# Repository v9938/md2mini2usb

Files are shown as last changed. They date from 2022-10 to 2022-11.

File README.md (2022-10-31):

# MD/CyberStick to USB Converter (MD2mini2USB)<BR>Nintendo Switch/MegaDrivemini2 Cyberstickモード対応版  

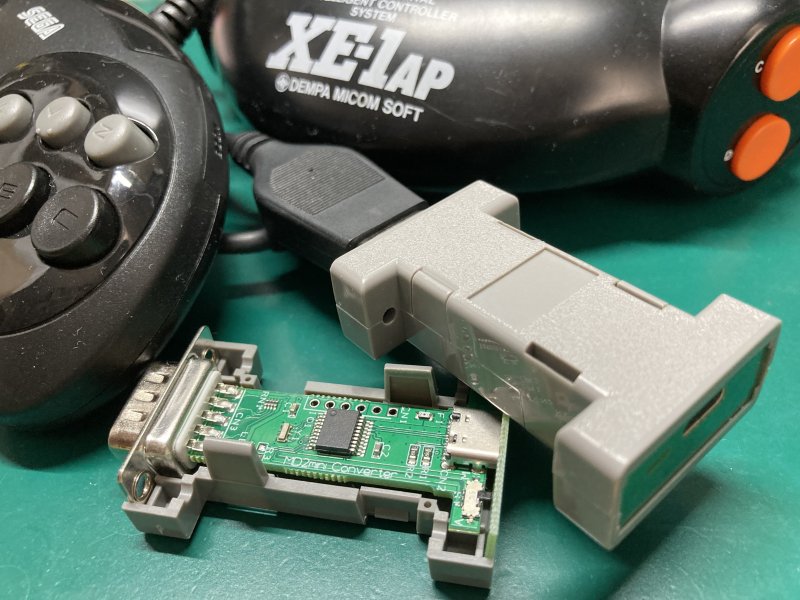
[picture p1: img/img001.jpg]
装置イメージ
  

**「メガドライブ2ミニ対応」 ←→ 「Ninetndo Switch対応」 の切り替えはファームウェア書換が必要です。**  

MD2mini2USBは、ジョイスティックコンバータです。  
メガドライブ対応コントローラ(3ボタン/6ボタン)・SHARP CyberStick(CZ-8NJ2),マイコンソフト XE-1AJ  
のプロトコルを変換し、DirectInput方式のUSBコントローラとして使える様にするコンバータです。  
元々は、メガドライブ2ミニ向けに制作していましたが、Nitendo Switchでも使用できる様になりました。  

現在、接続するゲーム機にあわせて2種類のファームウェアがあります。  
### メガドライブ2ミニ向けファームウェア  
下記コントローラ互換として動作します。  

* SEGA ファイティングパッド6B  
* マイコンソフト　サイバースティック XE1AJ1-USB  

**※ XE1AJ1-USBモードはMegaDrive2mini/Genesis2mini/PC接続のみ対応しています**

### Nintendo Switch向けファームウェア
下記コントローラ互換品として動作します。 

* HORI NSW-063(『ポッ拳 DX』専用コントローラー)  

## ■ 使用例
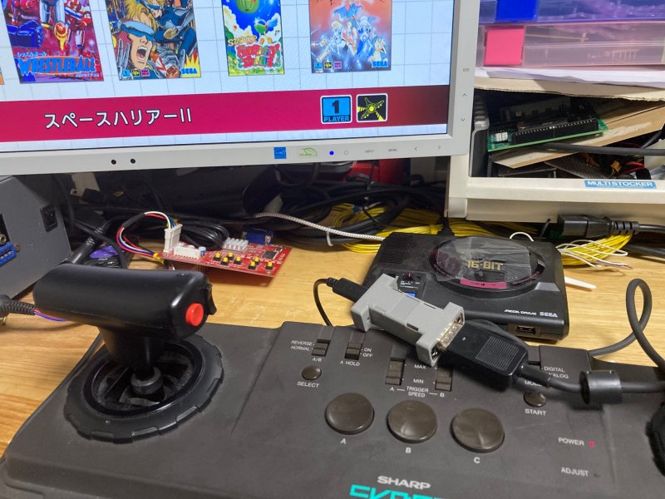
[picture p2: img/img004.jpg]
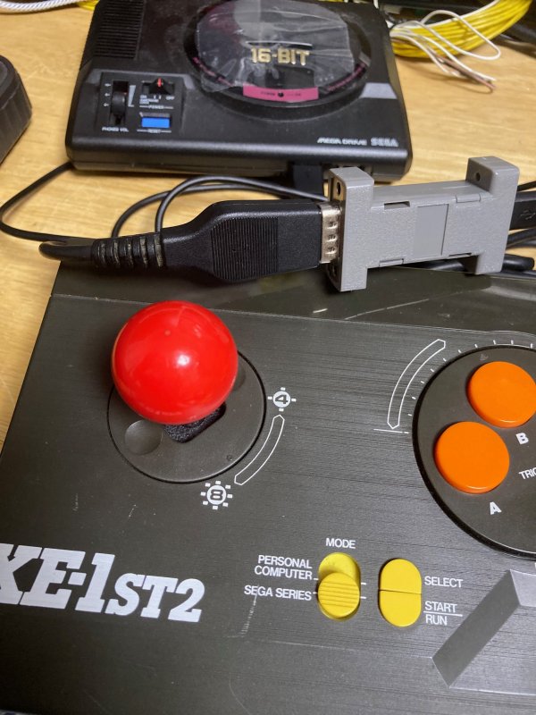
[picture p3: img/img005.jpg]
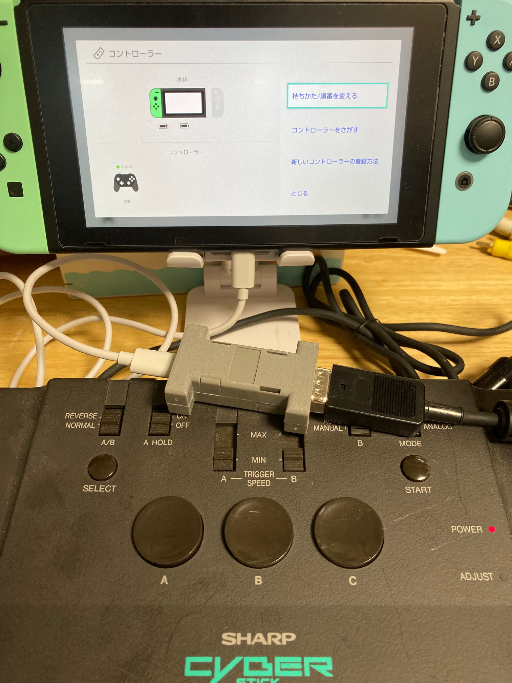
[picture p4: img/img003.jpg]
    

動画については下記URLを参照してください。  
<https://twitter.com/v9938/status/1580212775111909376?s=20&t=MJM-NV-31tJaAHmfy5s3Zw>
<https://twitter.com/v9938/status/1579874855343730689?s=20&t=MJM-NV-31tJaAHmfy5s3Zw>

## ■ 頒布について   

本製品はBoothおよび家電のKENちゃん、BEEPさんにて近日販売予定です。  
(Boothの発送は、週末にまとめて発送になるため、お急ぎの方は他ショップを利用ください)

### BEEP  

<https://www.beep-shop.com/ec/products/detail/28588>

### 家電のKENちゃん  

<https://www.kadenken.com/view/item/000000001480?category_page_id=ct169>

### Booth: (週１回の発送)  

<https://ifc.booth.pm/items/4229656>  
Boothでは先行品販売を実施しません [10/29以降 販売開始予定]  

## ■ 頒布品のメガドラミニ対応版とNintendo Switch対応版の違い

初期に書き込まれているファームウェアだけが異なります。ハードウェアに違いはありません。  
ユーザ側でファームウェアを書き換えることで、双方向の対応版を何回でも行き来できます。

## ■ 先行販売品について

先行販売版はXE1AJ-USBモードは仮実装になっています。  
メガドライブ2ミニ販売後に対応ファームウェアを公開する予定です。  

ユーザにて当該ファームウェアにアップデートをお願いします。  

## ■ 使用方法

1. D-SUB9Pin側に使いたいコントローラを接続します。
2. 先の細いものでコントローラモード切替スイッチを適切なモードにセットします。  
スイッチは、非常に壊れやすいので優しく取り扱いください。  
3. USBコネクタにケーブルを接続して、使用する機器に接続します。  

MegaDrive2miniでCyberStickモードを使う場合はCONTROLLER2に接続してください。　　

**メガドライブコントローラとCyberStickでは、コントローラ側の電源端子が異なります。**  
**コントローラモード切替スイッチは、本機の電源が入っていない状態で切り替えてください。**

| メガドライブコントローラモード | Cyberstickモード(MSX仕様) |  
| - | - |
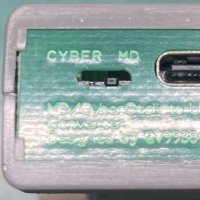
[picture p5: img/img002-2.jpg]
スイッチ位置MD
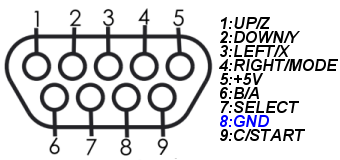
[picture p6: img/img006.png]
DSUB_MD
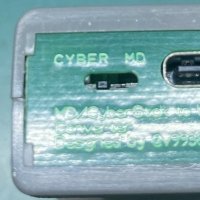
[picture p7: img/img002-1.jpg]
スイッチ位置ATARI
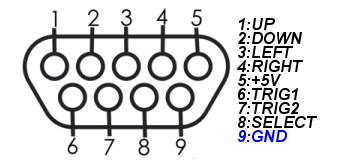
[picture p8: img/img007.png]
DSUB_ATARI
|    |   |

## ■ ボタン配置について

各オリジナルコントローラのボタン配置に準拠しています。設定ソフトにてボタン配置は変更可能です。  
変更した配置は、コントローラのBボタンを押しながらケーブル抜差（電源投入）を行う事で初期値になります。

初期値でのWindows PC上での配置は下記の通りです。

### ●メガドライブ2ミニ向けファームウェア ボタン配置

#### メガドライブコントローラモード(SEGA ファイティングパッド6B互換モード)  

| メガドライブコントローラ | USBコントローラ配置 | 制限事項など |  
| - | - | - |
| スティック | Ｘ軸Ｙ軸 |  |
| Ａ、Ｂ、Ｃボタン | ボタン３、２、６|  |
| Ｘ、Ｙ、Ｚボタン | ボタン４、１、５ | 6ボタン対応コントローラーのみ有効 |
| ＭＯＤＥボタン | ボタン７ | 6ボタン対応コントローラーのみ有効 |
| スタートボタン | ボタン８ |  |

#### CyberStickモード(XE1AJ1-USB互換モード)  

| CyberStick | USBコントローラ配置 | 制限事項など |  
| - | - | - |
| スティック | Ｘ軸Ｙ軸 |  |
| スロットル前後 | Ｚ回転 |  |
| トリガボタンＡ、Ｂ、Ｃ | ボタン１、２、３ |  |
| トリガボタンＤ、Ｅ１、Ｅ２ | ボタン４、５、６ |  |
| トリガボタンＡ'、Ｂ' | ボタン１、２ |  |
| セレクト、スタートボタン | ボタン７、８ | CZ-8NJ2のデジタルモードでは使用できません。 |

#### CyberStickモード(SEGA ファイティングパッド6B互換モード　※Aボタンを押しながらUSBを接続)  

| CyberStick | USBコントローラ配置 | 制限事項など |  
| - | - | - |
| スティック | Ｘ軸Ｙ軸 |  |
| スロットル前後 | － |  |
| トリガボタンＡ、Ｂ、Ｃ | ボタン３、２、７ |  |
| トリガボタンＤ、Ｅ１、Ｅ２ | ボタン４、１、６ |  |
| トリガボタンＡ'、Ｂ' | ボタン３、２ |  |
| セレクト、スタートボタン | ボタン９、１０ | CZ-8NJ2のデジタルモードでは使用できません。 |

### ●Nintendo SWITCH向けファームウェア ボタン配置

#### メガドライブコントローラモード  

| メガドライブコントローラ | コントローラ配置 | 制限事項など |  
| - | - | - |
| スティック | 左アナログスティックＸＹ軸 |  |
| Ａ、Ｂ、Ｃボタン | ボタンＡ、Ｂ、Ｒ|  |
| Ｘ、Ｙ、Ｚボタン | ボタンＸ、Ｙ、Ｌ | 6ボタン対応コントローラーのみ有効 |
| ＭＯＤＥボタン | ボタンＨＯＭＥ | 6ボタン対応コントローラーのみ有効 |
| スタートボタン | ボタン［＋］ |  |

#### CyberStickモード  

| CyberStick | コントローラ配置 | 制限事項など |  
| - | - | - |
| スティック | 左アナログスティックＸＹ軸 |  |
| スロットル前後 | 右アナログスティックＹ軸 |  |
| トリガボタンＡ、Ｂ、Ｃ | ボタンＡ、Ｂ、Ｙ |  |
| トリガボタンＤ、Ｅ１、Ｅ２ | ボタンＸ、Ｒ、Ｌ |  |
| トリガボタンＡ'、Ｂ' | ボタンＡ、Ｂ |  |
| セレクト、スタートボタン | ボタンＨＯＭＥ、［＋］ | CZ-8NJ2のデジタルモードでは使用できません。 |

## ■ 変換遅延について

変換にかかる内部処理時間は、一番時間がかかるメガドライブ6ボタンパッドで使用時で8.5us程度です。  
いずれのモードでもLow Speed USB規格の最小通信単位である1frame(1ms)以内で完了していることを確認しています。  
そのため規格上は変換遅延が無いことになります。  

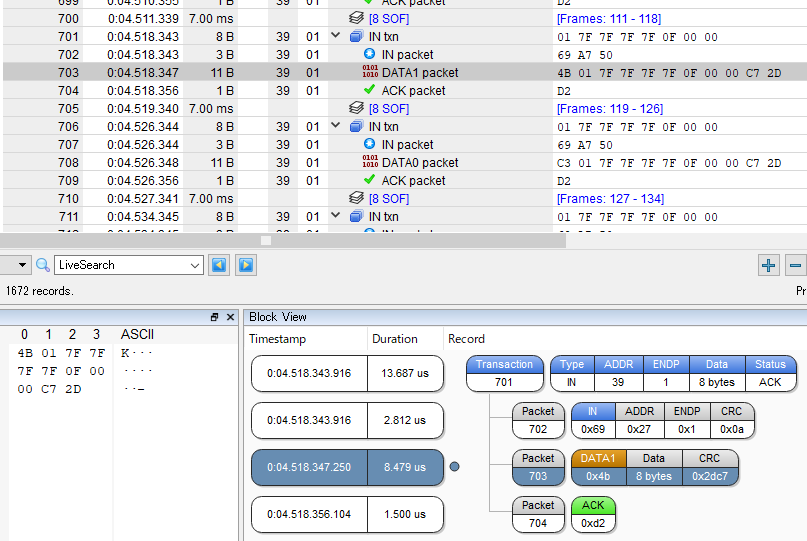
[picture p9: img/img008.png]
USBパケット


## ■ その他の注意点  

オリジナルのコントローラは製造後２０年以上経っています。  
動作不安定の場合は接続コントローラが正常に動作するかを確認をお願いします。

他の接続機器に影響がある場合があるのでコントローラはUSB接続前に接続してください。

コントローラモード切替スイッチ設定を誤ると回路保護のため一定時間電源が入らなくなる場合があります。  
その場合は、数分程度放置後再度接続する様にお願いします。  

## ■ ファームウェアアップデートについて(頒布版のみ対応)

本製品はファームウェアアップデートに対応しています。  
ファームウェアアップデートについては、Windows PCが必要になります。  

1. デバイスを一度取り外します。  
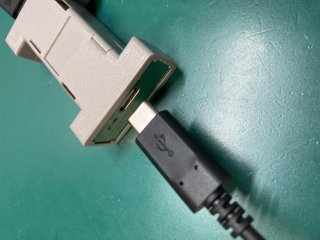
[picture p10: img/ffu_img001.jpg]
FFU1
  

2. Firmware Updateソフトを実行します。デバイスの接続待ち表示になります。  
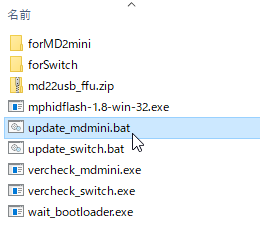
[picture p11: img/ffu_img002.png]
  FFU3  

3. 対応コントローラの［Cボタン］を押したままWindows PCに接続します。  
（コントローラモードスイッチは接続するコントローラに合わせてください。）  
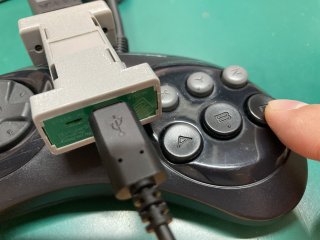
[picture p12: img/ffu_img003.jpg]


4. 正常に認識されると自動的にファームウェア更新が実行されます。  
認識されない場合は3からの手順を実施してください。　　
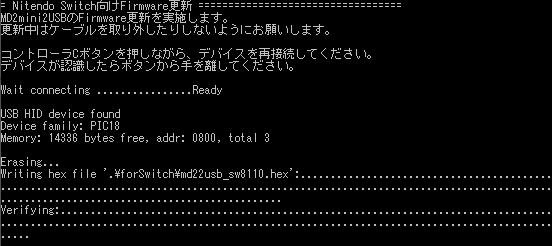
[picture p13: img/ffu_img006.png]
  
5. ファームウェア更新完了表示が出たら、一度デバイスを取り外します。  
更新後、設定の状態によってボタンが正常に動作しない場合があります。  
その場合はBボタンを押しながらUSBケーブルを抜き差しを行いE2PROMを初期化してください。
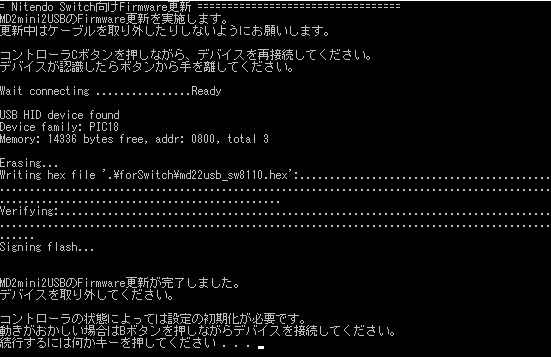
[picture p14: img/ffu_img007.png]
  

### ファームウェア更新/書換ツール

下記URLにてファームウェア更新/書換に必要なツールとファイル一式を頒布しています。  
<https://github.com/v9938/md2mini2usb/raw/main/FFU/md22usb_ffu.zip>

ZIPファイルを解凍後に、下記バッチファイルを実行してください。  

`./FFU/update_mdmini.bat`　メガドライブ2ミニ向けファームウェア更新  
`./FFU/update_switch.bat`　Nintendo Switch向けファームウェア更新  

### ファームウェアVersion確認方法  

ファームウェアVersionについては上記Firmware Updateソフト解凍後に下記手順で確認可能です。

1. 接続しているコントローラを外します。
2. コントローラモード切替スイッチをCyber側にします。
3. Windows PCに接続します。
4. Version確認ソフトで確認します。  

`./FFU/vercheck.exe`

実行画面  

謝辞：  
PID/UIDは、Microchipサブライセンスプログラムにより提供されたものを使用しています。  
ファームウェアアップデート機能には、 莎華(SAKA)さんのHID Bootloader (pic18Non-J)を利用しています。  
<http://www3.airnet.ne.jp/saka/hardware/pic-bootloader/pic-bootloader01.html>  

## ■ XE1AJ1-USB設定ソフトについて

マイコンソフトさんの設定ソフトはBootloaderモードで設定しているため、本製品では使用できません。  
遊び値や移動量設定ができるツールを別途用意しているのでそちらを使用してください。  

※テスト用ツールのXE1AJ-USB_TEST.exe/XE1AJ-USB_TEST_MINI.exeは使えます。  

## ■ ボタン配置について（メガドラミニ用)
ボタン設定ソフトを実行することで各モードでのボタン配置やスティックの遊びや移動量を変更することが可能です。  
設定値は、本体に記録されます。  

メガドライブミニ用ファームウェア向け設定用ソフト
<https://github.com/v9938/md2mini2usb/raw/main/keyconfig/keyconfigMd.exe>  

設定は下記手順で可能です。

1. 接続しているコントローラを外します。
2. コントローラモード切替スイッチをCyber側にします。
3. Windows PCに接続します。
4. 上記ソフトを実行します。

実行すると下記メニューがでます。  
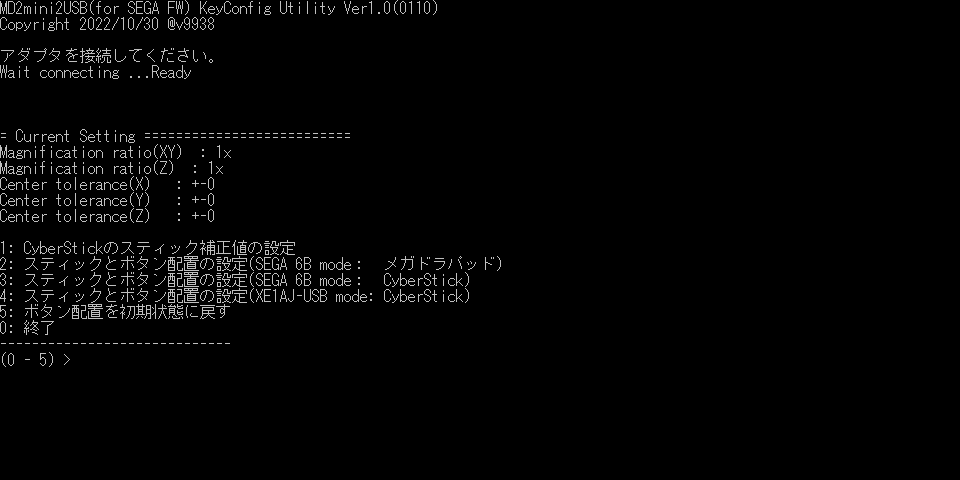
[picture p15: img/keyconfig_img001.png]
  

### メニュー説明  
#### 1: CyberStickのスティック補正値の設定  
アナログコントローラのセンターの遊び量と移動量設定(1～2倍)を設定できます。  
設定は、ジョイスティックのX,Y、Throttleのそれぞれで設定ができます。

#### 2: スティックとボタン配置の設定(SEGA 6B mode：  メガドラパッド)  
メガドライブパッドを接続した時のボタン配置を設定できます。  
ボタン番号はWindows PC上でのボタン番号と一致しています。  
スティックの設定は変更できません。

#### 3: スティックとボタン配置の設定(SEGA 6B mode：  CyberStick)  
SEGA ファイティングパッド6Bモード時のCyberStickのボタン配置を設定できます。  
ボタン番号はWindows PC上でのボタン番号と一致しています。
ジョイスティック、Throttleスティックの設定および値の反転設定ができます。  
ただし、XY Stickは一つしか無い為、どちらかのみが有効になります。  

#### 4: スティックとボタン配置の設定(XE1AJ-USB mode: CyberStick)  
XE1AJ-USBモード時のCyberStickのボタン配置を設定できます。  
ボタン番号はWindows PC上でのボタン番号と一致しています。  
ジョイスティック、Throttleスティックの割りあて設定および値の反転設定ができます。  
XY Stick/Z Stick/Hat Switchに割り当て可能です。重複設定した場合はいずれかのみが有効になります。  

#### 5: ボタン配置を初期状態に戻す  
ボタン配置とコントローラをすべて初期状態に戻します。  

## ■ ボタン配置について（SWITCH用)
ボタン設定ソフトを実行することで各モードでのボタン配置やスティックの遊びや移動量を変更することが可能です。  
設定値は、本体に記録されます。  

Switch用ファームウェア向け設定用ソフト
<https://github.com/v9938/md2mini2usb/raw/main/keyconfig/keyconfigSwitch.exe>  

設定は下記手順で行います。
1. 接続しているコントローラを外します。
2. コントローラモード切替スイッチをCyber側にします。
3. Windows PCに接続します。
4. 上記ソフトを実行します。

### メニュー説明
#### 1: CyberStickのスティック補正値の設定  
アナログコントローラのセンターの遊び量と移動量設定(1～2倍)を設定できます。  
設定は、ジョイスティックのX,Y、Throttleのそれぞれで設定ができます。

#### 2: 2: スティックとボタン配置の設定(SEGAメガドラパッド)  
メガドライブパッドを接続した時のボタン配置を設定できます。  
ボタンはSWITCHのボタンに合わせた案内が出るので番号を選択して設定してください。
ジョイスティックの設定ができます。  
L Stick/R Stick/Hat Switchに割り当て可能です。重複設定した場合はいずれかのみが有効になります。  

#### 3: スティックとボタン配置の設定(CyberStick)  
CyberStick接続時のボタン配置を設定できます。  
ボタンはSWITCHのボタンに合わせた案内が出るので番号を選択して設定してください。
ジョイスティック、Throttleスティックの設定ができます。  
L Stick/R Stick/Hat Switchに割り当て可能です。重複設定した場合はいずれかのみが有効になります。  

## ■ 誤ったボタン配置設定をしてしまった場合  
Bボタンを押しながらUSBケーブルを抜き差しを行いE2PROMを初期化してください。  
初期状態に戻す事が可能です。

## ■ GitHub公開データについて

ファームウェア：　　 <https://github.com/v9938/md2mini2usb/tree/main/firmware>  
回路図/基板データ：　<https://github.com/v9938/md2mini2usb/tree/main/PCB>

ファームウェアのコンパイルにはMicrochipのUSB library 'mla v2017_03_06'が必要です。  
頒布版とコードが異なりファームウェアアップデート機能が非対応になります。  

自作される場合は、秋月電子さんのマイコンボードを使うと良いと思います。  
<http://akizukidenshi.com/catalog/g/gK-05499/>  

## ■ 本機の仕様について

|仕様  | 詳細 |
| - | - |
| 使用マイコン | Microchip PIC18F14K50 |
| 定格 | 5V 50mA (ポリヒューズ250mA)|
| コントローラ規格 | USB2.0 HIDゲームコントローラ準拠(Direct Input方式) |
| キースキャン間隔<BR>(SEGA ファイティングパッド6B互換モード) | 10ms(設定値)/8ms(実測値) |  
| キースキャン間隔<BR>(XE1AJ-USB互換モード時) | 1ms(設定値)/1ms(実測値) |
| IN パケット応答時間 | メガドライブ6ボタンパッド使用時 8.5us(実測値)<BR>CyberStick使用時 8.4us(実測値) |
| 対応コントローラ | メガドライブ規格準拠コントローラ(8pin GND)<BR>MSX規格準拠コントローラ(9pin GND) |
| 動作確認環境 | Windows11/10/7<BR>SEGA MegaDrive mini/Genesis mini<BR>SEGA MegaDrive2 mini/Genesis2 mini<BR>Nintendo SWITCH |
| 動作確認済みコントローラー | SEGA SJ-3500<BR>SEGA SJ-6000<BR>マイコンソフト XE-1ST2<BR>マイコンソフト XE-1AP (PERSONAL COMPUTERモード)<BR>マイコンソフト XE-1AP (メガドラモード)<BR>SHARP CZ-8NJ2 (CYBER STICK)<BR>FUJITSU FMT-PD102 |

## ■ 制約事項
Firmware version 1.00～  
MSX仕様のジョイスティックでも使用可能ですが、かならず2つのキー入力になります。  
Firmware version 1.20～  
マイコンソフト XE-1AP (メガドラモード)に対応しましたが、アナログモードのみの対応になります。

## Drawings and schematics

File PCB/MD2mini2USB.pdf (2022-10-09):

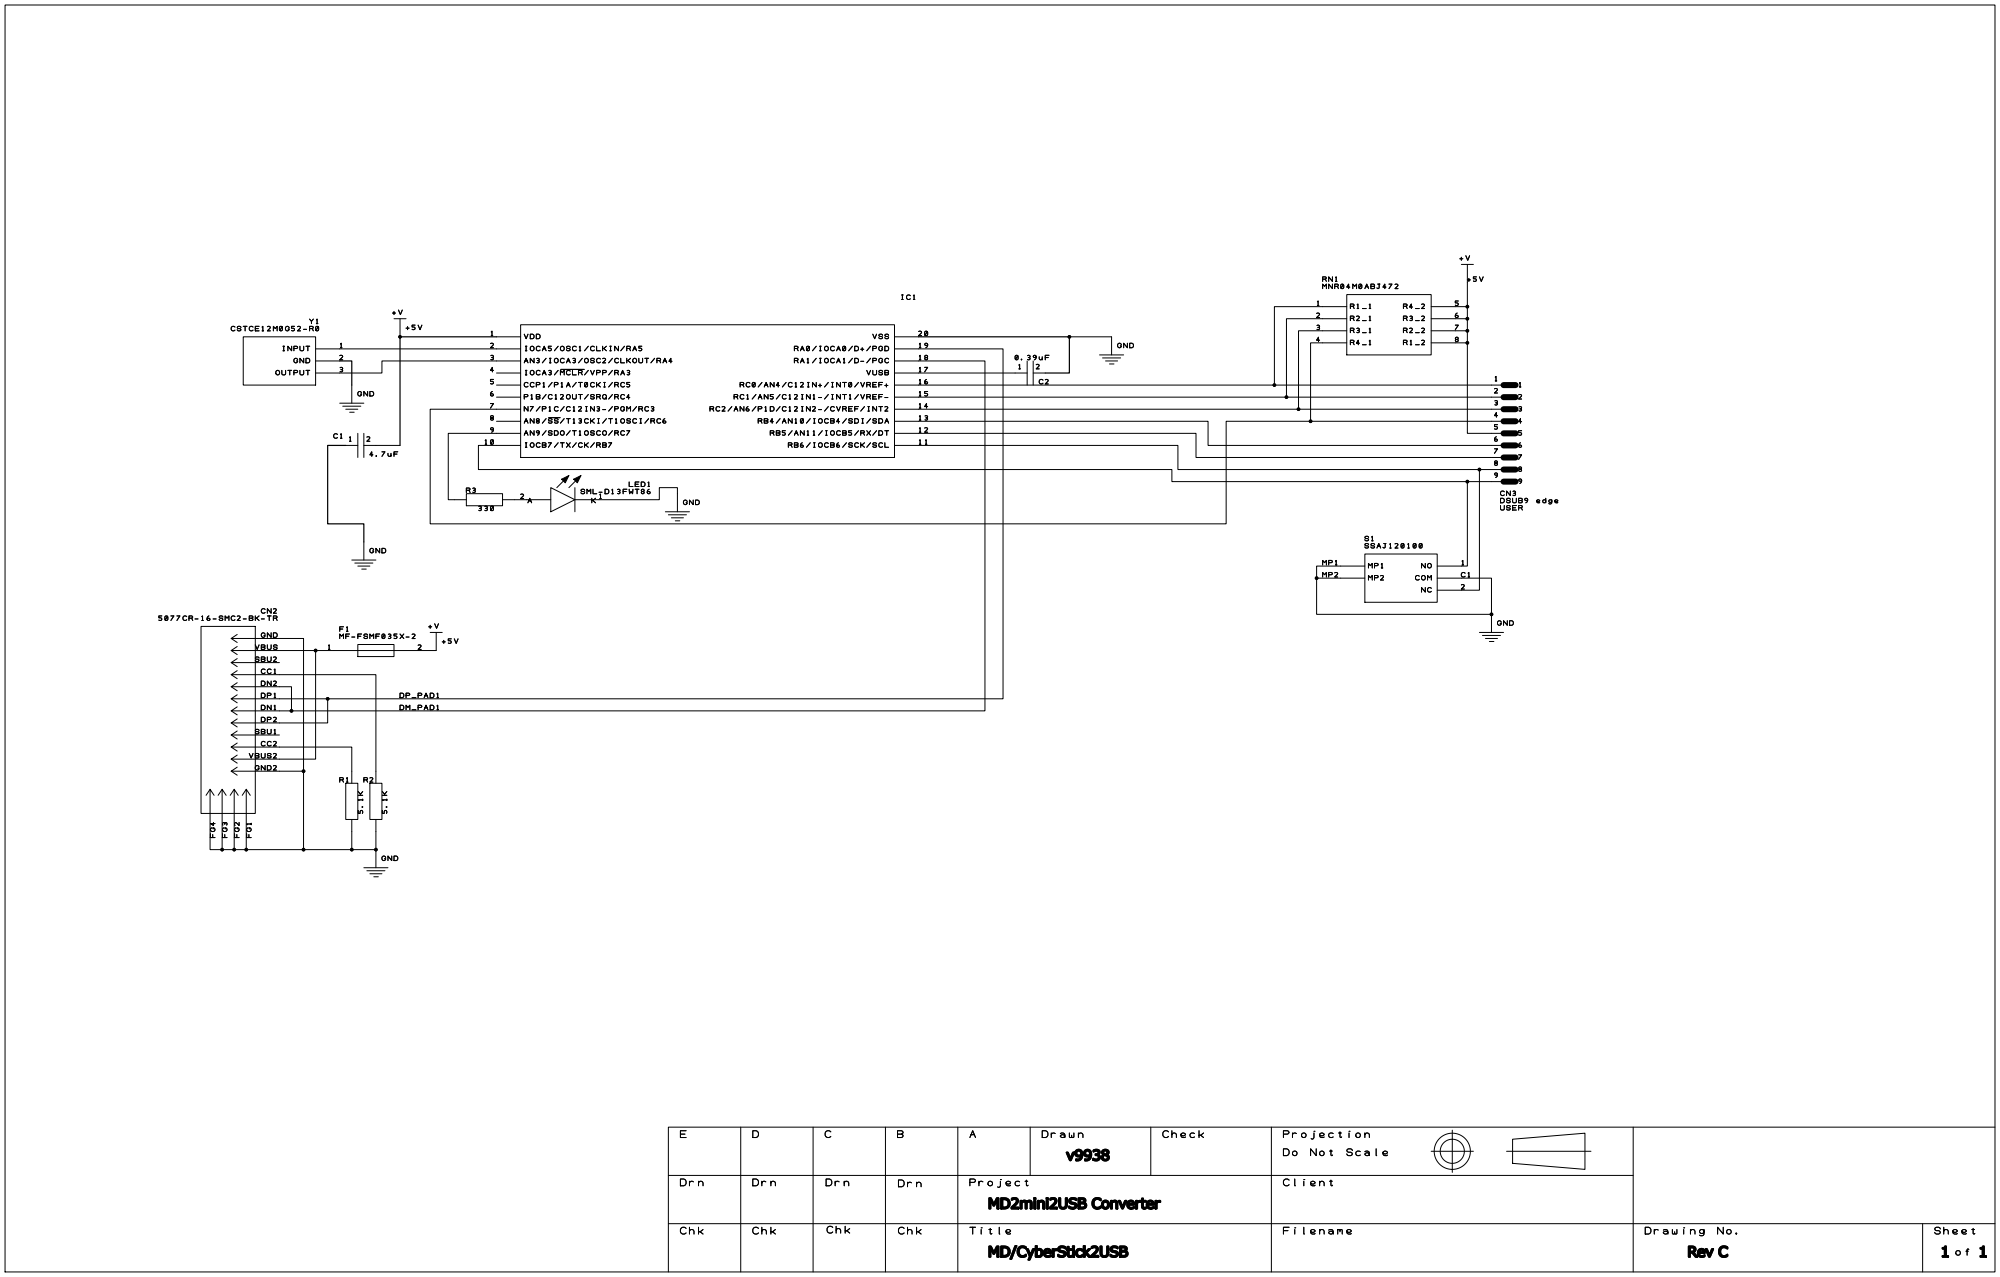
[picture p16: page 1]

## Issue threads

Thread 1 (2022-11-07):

ボタン設定ソフトのメニュー4、Throttle設定で4以上の値が入力できない。

v9938, 2022-11-07:
> 0:変更なし 1:[X Stick] 2:[Y Stick] 3:[Z Stick] 4:[Zr Stick] 5:[HAT X] 6:[HAT Y]
> (0-3)?

上記表示で4以上の設定ができません。

v9938, 2022-11-07:
入力閾値確認値の設定ミス。修正予定

v9938, 2022-11-14:
V1.40で修正済

Closed 2022-11-14.

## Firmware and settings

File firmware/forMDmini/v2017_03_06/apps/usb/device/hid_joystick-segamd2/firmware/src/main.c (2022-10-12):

/********************************************************************
 Software License Agreement:

 The software supplied herewith by Microchip Technology Incorporated
 (the "Company") for its PIC(R) Microcontroller is intended and
 supplied to you, the Company's customer, for use solely and
 exclusively on Microchip PIC Microcontroller products. The
 software is owned by the Company and/or its supplier, and is
 protected under applicable copyright laws. All rights are reserved.
 Any use in violation of the foregoing restrictions may subject the
 user to criminal sanctions under applicable laws, as well as to
 civil liability for the breach of the terms and conditions of this
 license.

 THIS SOFTWARE IS PROVIDED IN AN "AS IS" CONDITION. NO WARRANTIES,
 WHETHER EXPRESS, IMPLIED OR STATUTORY, INCLUDING, BUT NOT LIMITED
 TO, IMPLIED WARRANTIES OF MERCHANTABILITY AND FITNESS FOR A
 PARTICULAR PURPOSE APPLY TO THIS SOFTWARE. THE COMPANY SHALL NOT,
 IN ANY CIRCUMSTANCES, BE LIABLE FOR SPECIAL, INCIDENTAL OR
 CONSEQUENTIAL DAMAGES, FOR ANY REASON WHATSOEVER.
 *******************************************************************/

/** INCLUDES *******************************************************/
#include "system.h"

#include "usb.h"
#include "usb_device_hid.h"

#include "app_device_joystick.h"



MAIN_RETURN main(void)
{
    SYSTEM_Initialize(SYSTEM_STATE_USB_START);
    APP_DeviceJoystickCheckConnect();
    USBDeviceInit();
    USBDeviceAttach();

    while(1)
    {
        SYSTEM_Tasks();

        #if defined(USB_POLLING)
            // Interrupt or polling method.  If using polling, must call
            // this function periodically.  This function will take care
            // of processing and responding to SETUP transactions
            // (such as during the enumeration process when you first
            // plug in).  USB hosts require that USB devices should accept
            // and process SETUP packets in a timely fashion.  Therefore,
            // when using polling, this function should be called
            // regularly (such as once every 1.8ms or faster** [see
            // inline code comments in usb_device.c for explanation when
            // "or faster" applies])  In most cases, the USBDeviceTasks()
            // function does not take very long to execute (ex: <100
            // instruction cycles) before it returns.
            USBDeviceTasks();
        #endif

        /* If the USB device isn't configured yet, we can't really do anything
         * else since we don't have a host to talk to.  So jump back to the
         * top of the while loop. */
        if( USBGetDeviceState() < CONFIGURED_STATE )
        {
            /* Jump back to the top of the while loop. */
            continue;
        }

        /* If we are currently suspended, then we need to see if we need to
         * issue a remote wakeup.  In either case, we shouldn't process any
         * keyboard commands since we aren't currently communicating to the host
         * thus just continue back to the start of the while loop. */
        if( USBIsDeviceSuspended() == true )
        {
            /* Jump back to the top of the while loop. */
            continue;
        }

        //Application specific tasks
        APP_DeviceJoystickTasks();

    }//end while
}//end main


/*******************************************************************
 * Function:        bool USER_USB_CALLBACK_EVENT_HANDLER(
 *                        USB_EVENT event, void *pdata, uint16_t size)
 *
 * PreCondition:    None
 *
 * Input:           USB_EVENT event - the type of event
 *                  void *pdata - pointer to the event data
 *                  uint16_t size - size of the event data
 *
 * Output:          None
 *
 * Side Effects:    None
 *
 * Overview:        This function is called from the USB stack to
 *                  notify a user application that a USB event
 *                  occured.  This callback is in interrupt context
 *                  when the USB_INTERRUPT option is selected.
 *
 * Note:            None
 *******************************************************************/
bool USER_USB_CALLBACK_EVENT_HANDLER(USB_EVENT event, void *pdata, uint16_t size)
{
    switch( (int) event )
    {
        case EVENT_TRANSFER:
            Nop();
           break;

        case EVENT_SOF:
            break;

        case EVENT_SUSPEND:
            //Call the hardware platform specific handler for suspend events for
            //possible further action (like optionally going reconfiguring the application
            //for lower power states and going to sleep during the suspend event).  This
            //would normally be done in USB compliant bus powered applications, although
            //no further processing is needed for purely self powered applications that
            //don't consume power from the host.
            SYSTEM_Initialize(SYSTEM_STATE_USB_SUSPEND);
            break;

        case EVENT_RESUME:
            //Call the hardware platform specific resume from suspend handler (ex: to
            //restore I/O pins to higher power states if they were changed during the 
            //preceding SYSTEM_Initialize(SYSTEM_STATE_USB_SUSPEND) call at the start
            //of the suspend condition.
            SYSTEM_Initialize(SYSTEM_STATE_USB_RESUME);
            break;

        case EVENT_CONFIGURED:
            /* When the device is configured, we can (re)initialize the demo
             * code. */
            APP_DeviceJoystickInitialize();
            break;

        case EVENT_SET_DESCRIPTOR:
            break;

        case EVENT_EP0_REQUEST:
            /* We have received a non-standard USB request.  The HID driver
             * needs to check to see if the request was for it. */
            USBCheckHIDRequest();
            break;

        case EVENT_BUS_ERROR:
            break;

        case EVENT_TRANSFER_TERMINATED:
            break;

        default:
            break;
    }
    return true;
}

/*******************************************************************************
 End of File
*/

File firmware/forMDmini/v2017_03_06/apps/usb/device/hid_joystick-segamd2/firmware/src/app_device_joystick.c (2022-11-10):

//
//  SEGA MDmini Converter2 
//  - MD/CyberStick to USB Converter -
//
//  MegaDrivemini2 Cyberstickモード対応版  
//  Copyright 2022 @v9938
//
//  メガドライブ対応コントローラ(3B/6B),
//	SHARP CyberStick(CZ-8NJ2),マイコンソフト XE-1AJを
//  DirectInput方式のUSBコントローラとして使える様にするコンバータです。  
//

// MicroChipのライセンス
/********************************************************************
 Software License Agreement:

 The software supplied herewith by Microchip Technology Incorporated
 (the "Company") for its PIC(R) Microcontroller is intended and
 supplied to you, the Company's customer, for use solely and
 exclusively on Microchip PIC Microcontroller products. The
 software is owned by the Company and/or its supplier, and is
 protected under applicable copyright laws. All rights are reserved.
 Any use in violation of the foregoing restrictions may subject the
 user to criminal sanctions under applicable laws, as well as to
 civil liability for the breach of the terms and conditions of this
 license.

 THIS SOFTWARE IS PROVIDED IN AN "AS IS" CONDITION. NO WARRANTIES,
 WHETHER EXPRESS, IMPLIED OR STATUTORY, INCLUDING, BUT NOT LIMITED
 TO, IMPLIED WARRANTIES OF MERCHANTABILITY AND FITNESS FOR A
 PARTICULAR PURPOSE APPLY TO THIS SOFTWARE. THE COMPANY SHALL NOT,
 IN ANY CIRCUMSTANCES, BE LIABLE FOR SPECIAL, INCIDENTAL OR
 CONSEQUENTIAL DAMAGES, FOR ANY REASON WHATSOEVER.
 *******************************************************************/

#ifndef USBJOYSTICK_C
#define USBJOYSTICK_C



/** INCLUDES *******************************************************/
#include "usb.h"
#include "usb_device_hid.h"
#include "system.h"
#include "stdint.h"
#include <xc.h>


#define _XTAL_FREQ 48000000 // delay用に必要(クロック12MHzを指定)

#define _delay(x) _delay((unsigned long)((x)))
#define _delay_us(x) _delay((unsigned long)((x)*(_XTAL_FREQ/4000000UL)))
#define _delay_ms(x) _delay((unsigned long)((x)*(_XTAL_FREQ/4000UL)))


#define TIMEOUTMAX 200
#define ERR_TIMEOUT 1
#define ERR_NONE 0

//スイッチ関係の設定
#define TRISMODE_EQMD		(TRISB == 0xD0)
#define DSUBPIN8_EQGND		(PORTBbits.RB6==0)
#define DSUBPIN9_EQGND		(PORTBbits.RB7==0)


#define MDMODE_LEDON        PORTCbits.RC7 = 1
#define MDMODE_LEDOFF       PORTCbits.RC7 = 0
#define MDMODE_EQON       	(PORTCbits.RC7 == 1)

#define CYBER_REQOFF        PORTBbits.RB6 = 1
#define CYBER_REQON         PORTBbits.RB6 = 0
#define CYBER_LH_EQHIGH   	(PORTBbits.RB4 == 1)
#define CYBER_ACK_EQHIGH  	(PORTBbits.RB5 == 1)
#define CYBER_LH_EQLOW    	(PORTBbits.RB4 == 0)
#define CYBER_ACK_EQLOW   	(PORTBbits.RB5 == 0)

#define CYBERMD_REQOFF        PORTBbits.RB5 = 1
#define CYBERMD_REQON         PORTBbits.RB5 = 0
#define CYBERMD_LH_EQHIGH   	(PORTBbits.RB4 == 1)
#define CYBERMD_ACK_EQHIGH  	(PORTBbits.RB7 == 1)
#define CYBERMD_LH_EQLOW    	(PORTBbits.RB4 == 0)
#define CYBERMMD_ACK_EQLOW   	(PORTBbits.RB7 == 0)

#define E2PROM_MAGICNUM		0xA3
//3Bモードの長押しLOOP数 8ms*400 =約3.2秒
#define MD3B_MODE_TIMEOUT	400
//連射ON/OFFのMODE/SELECTスイッチの長押しLOOP数 16ms*255 =約5秒
#define RAPIDSW_TIMEOUT 	313

#define HID_INTERVAL_1MS        1
#define HID_INTERVAL_2MS        2
#define HID_INTERVAL_4MS        3
#define HID_INTERVAL_8MS        4

#define FRAME_RATE_US			16685
#define USB_RATE_US				16000

///////////////////////////////////////////////////////////////////////
// Global Value
///////////////////////////////////////////////////////////////////////
unsigned char IncomingHIDCBSetReport =0;
unsigned char CyberData[14];			//
unsigned short Md3bModeSWCount;			// 3ボタンモードのスタートボタン長押しのカウント
unsigned short sDataModeSWCountOut;		// スタートボタン長押しのカウントのタイムアウト値(8ms x タイムアウト値)
unsigned short sFrameDiffCount;			// コントローラのアクセス時間と実機のスキャン間隔との差分値
unsigned char bDataRapidSpeedA;			//連射ボタンの分周設定値(STEP1)
unsigned char bDataRapidSpeedB;			//連射ボタンの分周設定値(STEP2)
unsigned char RapidSpeedCount;			//連射ボタンの分周カウント

unsigned char RapidCount;				// 連射テーブルのカウンター
unsigned char RapidCountOut;			// 連射テーブルの切り替えカウント値
unsigned char RapidTable;				// 連射テーブルの選択テーブル番号
unsigned char RapidEnable;				// 連射有効/無効スイッチ
unsigned char RapidStart;				// 連射Start flag
unsigned short RapidSWCount;			// 連射有効化/無効化までのSELECT長押しのカウント
unsigned short bRapidSWCountOut;		// 連射有効化/無効化までのSELECT長押しのカウント設定値


int CyberMode;							// CyberStickの入力状態 (0=正常[アナログモード] 1=TIMEOUT[デジタルモード])
int XE1APMode;							// XE1AP(メガドラモード）フラグ

uint8_t centerX,centerY,centerZ;		// CyberStickの入力の中心遊び値
uint8_t muxXY, muxZ;					// CyberStickの移動量(1=0.5x,2=1.0x,3=1.5x,4=2.0x)
unsigned short slewX,slewY,slewZ;		// 設定値から計算できる増分値

///////////////////////////////////////////////////////////////////////
// Global Value ボタンのマスクデータ
///////////////////////////////////////////////////////////////////////
unsigned char bDataCyber[20];			//CyberStickモード用
unsigned char bDataCyMDmode[20];		//CyberStick(MD6B)モード用
unsigned char bDataCyMDXY;				//CyberStick(MD6B)モード用XY格納位置番号
unsigned char bDataCyMDZ;				//CyberStick(MD6B)モード用Z格納位置番号
unsigned char bDataCyberXY;				//CyberStickモード用XY格納位置番号
unsigned char bDataCyberZ;				//CyberStickモード用Z格納位置番号
unsigned char bDataCyberRvXYZ;			//CyberStickモード用XYZ反転フラグ
unsigned char bDataMD6B[16];			//Fighting Pad 6Bモード用
unsigned char bDataMD6BXY ;				//Fighting Pad 6Bモード用XY格納位置番号

unsigned char bDataMD6BRapid[4];		//Fighting Pad 6Bモード用連射ボタン設定
unsigned char bDataCyberRapid[4];		//CyberStickモード用連射ボタン設定
unsigned char DataMD6BRapidMask[2];		//Fighting Pad 6Bモード用連射ボタンマスク値
unsigned char DataCyberRapidMask[2];	//CyberStickモード用連射ボタンマスク値



//Cyber Stick ボタンデータ配置
// val4/cal5
// 0/1: 		Aボタンの配置情報
// 2/3: 		Bボタンの配置情報
// 4/5: 		Cボタンの配置情報
// 6/7: 		Dボタンの配置情報
// 8/9: 		E1ボタンの配置情報
// 10/11: 		E2ボタンの配置情報
// 12/13: 		Startボタンの配置情報
// 14/15: 		Selectボタンの配置情報
// 16/17: 		A'ボタンの配置情報
// 18/19: 		B'ボタンの配置情報




//MD6B ボタンデータ配置
// val4/cal5
// 0/1: 		Aボタンの配置情報
// 2/3: 		Bボタンの配置情報
// 4/5: 		Cボタンの配置情報
// 6/7: 		Xボタンの配置情報
// 8/9: 		Yボタンの配置情報
// 10/11: 		Zボタンの配置情報
// 12/13: 		Startボタンの配置情報
// 14/15: 		MODEボタンの配置情報

#define MD6B_A						0
#define MD6B_B						2
#define MD6B_C						4
#define MD6B_X						6
#define MD6B_Y						8
#define MD6B_Z						10
#define MD6B_START					12
#define MD6B_MODE					14

#define CYBER_A						0
#define CYBER_B						2
#define CYBER_C						4
#define CYBER_D						6
#define CYBER_E1					8
#define CYBER_E2					10
#define CYBER_START					12
#define CYBER_SELECT				14
#define CYBER_Ad					16
#define CYBER_Bd					18

//XYZのIN PACKET位置
#define MD6B_XY_STICK				0x3
#define MD6B_Z_STICK				0x2

#define CYBER_XY_STICK				0x3
#define CYBER_Z_STICK				0x6
#define CYBER_HAT_STICK				0x2

//ボタンのIN PACKETフラグ位置
#define MD6B_BUTTON1_ON				0x10
#define MD6B_BUTTON2_ON				0x20
#define MD6B_BUTTON3_ON				0x40
#define MD6B_BUTTON4_ON				0x80
#define MD6B_BUTTON5_ON				0x01
#define MD6B_BUTTON6_ON				0x02
#define MD6B_BUTTON7_ON				0x04
#define MD6B_BUTTON8_ON				0x08
#define MD6B_BUTTON9_ON				0x10
#define MD6B_BUTTON10_ON			0x20
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

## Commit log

2022-10-09 Beta Release
    Release for pre-sale (MI68) version
    [MD2USB - Bottom Copper (Resist).gbr, MD2USB - Bottom Copper.gbr, MD2USB - Drill Ident Drawing - [Through Hole].gbr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]
2022-10-12 Add Nintendo Switch mode firmware/FFU Tool
    Nintendo Switch向けのコードおよびFFUツールを追加しました。
2022-10-13 Change E2PROM handling
    MDmini Ver0.5 -> MDmini Ver0.6のFFU時にE2PROMのマニュアル初期化が必要だったのを修正。
    FFU用ZIPファイルを追加
2022-10-13 Support Hat pad (Nintendo Switch firmware)
    Nintendo Switch FWを更新
    Hat Switchに対応
    Versionを8110 に更新
    String descriptorの製品名を変更
    ボタン設定ソフトを変更
2022-10-13 Update md22usb_ffu.zip
    FFUのバイナリー更新忘れ
2022-10-14 Update README.md
    READMEを更新
    －FFU手順などのより詳細な内容を追加
    －URLの更新
2022-10-16 Support function get current button configuration. (SwitchFW 8120)
    SWITCH Firmware 8110 > 8120
    現在のボタン設定を読み取る機能をサポートしました。
2022-10-16 Update README.md
    スイッチ切り替え時の注意を追加した。
2022-10-17 Update README.md
    BEEPさんとKENちゃんの販売URLを追加
2022-10-27 Release Version1.00 firmware
    XE1AJ-USBモードに対応。
2022-10-30 Update MDmini firmware (1.00>1.10)
    MDmini 対応Firmwareを1.10にアップデート
    機能追加：
    KEYの配置変更が可能になりました。
    メガドラ３ボタンパッド使用時にStartボタン長押し３秒以上でMODEスイッチになります。
    XYZの反転が設定できる様になりました。
    その他：
    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
2022-10-31 Added MDMini2 vesion firmware source code
    MDmini2 Ver1.20のソースコードを追加
2022-10-31 Update README.md
    ボタン配置設定ソフトの使い方を追加しました。
    制約事項の章を追加しました。
2022-10-31 Updated to ver1.20 firmware
    下記機能を追加しました。
    - XE-1AP MDモードへの対応 (アナログモードのみ対応)
2022-11-01 Fixed CR code
    Batchファイルの改行コードがLFになってしまったのを修正しました。
2022-11-03 Add Configuration of the start button timeout for the 3-button SEGA MDPad.
    SEGA 3ボタンパッド使用時にStartボタン長押しモードでメニューを開くまでの時間を設定できる様にしました。
    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
2022-11-04 Add Trial firmware
    USBインターバルを1ms>8msに変更したファームをお試しでRelease
2022-11-04 Update md22usb_ffu.zip
    トライアルFWを追加
2022-11-05 Add firmware 1.30 (Add setting HID Interval for XE1AJ-USB mode )
    MDmini2モードのファームを更新(V1.25>V1.30)
    - HID Report Intervalを1ms/2ms/4ms/8msのいずれかに設定可能になりました。
    - Key設定ソフトウェアをアップデートしました。
2022-11-05 Update keyconfigMd.exe
    キー設定ソフトのバグを修正しました。
2022-11-06 MD firmware update V1.31 (BUGFIX)
    MDmini向けFirmware 1.30>1.31
    - CyberStickのSEGA6Bファイティングパッドモードのスティック設定できなかった不具合を修正
    ボタン設定ソフト
    - Ver1.31対応
    - ボタン設定の初期化後のメニュー遷移が想定と違ったため修正
    [app_device_joystick.c]
2022-11-06 Update keyconfigMd.exe
    バグ修正：
    メニュー番号に不整値をセットすると正常な値が入力されるまで表示が流れる不具合を修正
2022-11-06 Update keyconfigMd.exe/keyconfigSwitch.exe
    （修正漏れの修正）
    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
2022-11-07 Add firmware V1.40 (Add Synchronous Rapid for XE1AJ-USB mode )
    MDmini2モードのファームを更新(V1.40)
    ー USBパケット上でのシンクロ連射機能を追加
    ー CyberStickデジタルモード時にXYZ反転機能が動作しなかった不具合を修正した。
    キー設定ソフト
    - シンクロ連射機能の設定メニューを追加
    - ISSUE #1Throttle設定で4以上の値が入力できない。問題を修正
    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
    [app_device_joystick.c]
2022-11-07 Update md22usb_ffu.zip
    FFUのアーカイブの更新し忘れ
2022-11-09 Add firmware V1.41 (Add Rapid Speed & Enable/Disable )
    MDmini2モードのファームを更新(V1.41)
    ー シンクロ連射機能のショット数の設定を追加
    ー MODE/SELECTボタン長押しでシンクロ連射をON/OFFが可能になりました。
    ー メガドラモードでXE-1APを接続時、デジタルモードに切り替えると配置おかしくなるバグを修正
    - シンクロ連射機能に速度設定/設定の設定時間を追加
    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
    [app_device_joystick.c]
2022-11-10 Update to firmware V1.42 (Bugfix Rapid trigger)
    MDmini2モードのファームを更新(V1.42)
    ー シンクロ連射の初回STEPが実行されなかったり、設定時間以下になるバグを修正
    修正：
    - Ver1.42を設定対象に追加
    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
    [app_device_joystick.c]
